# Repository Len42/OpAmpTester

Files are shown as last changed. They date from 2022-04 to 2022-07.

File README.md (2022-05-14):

# Op Amp Tester

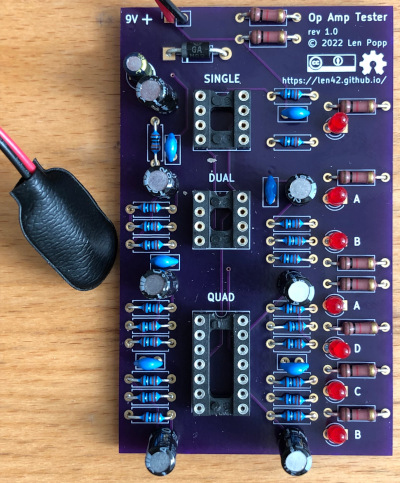
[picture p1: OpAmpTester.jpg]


This is a circuit that tests op amp chips to verify that they are working properly. You might find it useful if you repair old equipment, or if your prototype circuits don't always work the way you expect. 🔥😕

### Features

- Tests single, dual, and quad op amp DIP ICs that have the standard pinout
- LEDs blinking = op amps working!
- Powered by a 9-volt battery

### Usage

The circuit board has separate sockets for single, dual, and quad op amp ICs. To test a chip, insert it in the appropriate socket and plug in a 9-volt battery. The LED(s) next to the chip should start blinking. If one or more of the LEDs don't blink, the chip is bad.

### Notes

This tester can test just about any DIP op amp IC (single, dual, or quad) that can operate on a 9 volt power supply and that has the usual pinout. I have tried it with several chips including:
- TL071, TL074
- LM358
- OPA2134

The circuit is designed for a 9-volt power supply. Using a higher supply voltage may not work because the LEDs can't take much reverse voltage.

The PCB layout is provided in KiCad and gerber formats. The PCBs that I used can be ordered from OSH Park. The design is [here.](https://oshpark.com/shared_projects/9kqx3vmx)

I made a [parts list](OpAmpTester-BOM.csv) with links to specific parts and vendors, but most of the components are generic resistors, capacitors, and LEDs - it's not necessary to use the exact parts that I listed. I do recommend using good quality IC sockets because cheap ones are not designed for repeated IC insertion and removal.

Please note that I am a hobbyist, not a trained electronics engineer. No guarantees!

### References

This design is based on some other op amp testers:

- [Edison Science Corner](https://www.youtube.com/watch?v=aGswFkS5oHQ)  
- [NightFire Electronics](https://vakits.com/single-op-amp-tester-kit)  
- [Synthchaser](https://synthchaser.com/product/synthchaser-op-amp-tester/)  

### Software Used

[KiCad](https://www.kicad.org/) 6.0.4

<hr /><div><div style="xfloat:left; padding-left:10px;"><br />© 2022 Len Popp CC BY<br />This work is licensed under a <a rel="license" href="http://creativecommons.org/licenses/by/4.0/">Creative Commons Attribution 4.0 International License</a>.</div></div>

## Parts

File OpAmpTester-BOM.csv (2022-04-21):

Ref | Qty | Value | Value2 | Note | Description | Datasheet | Manufacturer | ManuPartNum | Distributor1 | DistributorPartNum1 | DistributorPartLink1 | Distributor2 | DistributorPartNum2 | DistributorPartLink2
C1 | 1 | 10U |  |  | Capacitor - Electrolytic | https://www.mouser.ca/datasheet/2/315/ABA0000C1218-1131230.pdf | Panasonic | ECA-1EM100I | Mouser | 667-ECA-1EM100I | https://www.mouser.ca/ProductDetail/Panasonic/ECA-1EM100I?qs=rMMd5vBiahoPyQAc8NWEpA%3D%3D
C2 C5 C6 C9 C10 C11 C12 | 7 | 1U |  |  | Capacitor - Electrolytic | https://www.mouser.ca/datasheet/2/231/161588148197-2307385.pdf | Lelon | SEA010M1HBK-0407P | Mouser | 140-SEA1R0M1HBK0407 | https://www.mouser.ca/ProductDetail/Lelon/SEA010M1HBK-0407P?qs=tsfqLUzc7IqlOdpxXJYLkw%3D%3D
C3 C4 C7 C8 C13 C14 | 6 | 100N |  |  | Capacitor - Ceramic - IC decoupling | https://product.tdk.com/system/files/dam/doc/product/capacitor/ceramic/lead-mlcc/catalog/leadmlcc_halogenfree_fg_en.pdf | TDK | FG18X7R1H104KNT06 | Mouser | 810-FG18X7R1H104KNT6 | https://www.mouser.ca/ProductDetail/810-FG18X7R1H104KNT6
D1 | 1 | 1N4001 |  |  | 50V 1A General Purpose Rectifier Diode, DO-41 | http://www.vishay.com/docs/88503/1n4001.pdf | onsemi | 1N4001RLG | Mouser | 863-1N4001RLG | https://www.mouser.ca/ProductDetail/onsemi/1N4001RLG?qs=y2kkmE52mdNtNRrsA1ylQg%3D%3D
D2 D3 D4 D5 D6 D7 D8 | 7 | LED |  |  | Light emitting diode | https://www.mouser.ca/datasheet/2/239/lite-on_lite-s-a0002934679-1-1737726.pdf | Lite-On | LTL-1CHE | Mouser | 859-LTL-1CHE | https://www.mouser.ca/ProductDetail/Lite-On/LTL-1CHE
J1 | 1 | V-IN |  |  | Generic connector, single row, 01x02, script generated (kicad-library-utils/schlib/autogen/connector/) | https://cdn-shop.adafruit.com/datasheets/00548.pdf |  |  | Adafruit | 598 | https://www.adafruit.com/product/598 | Mouser | 710-61303211821 | https://www.mouser.ca/ProductDetail/Wurth-Elektronik/61303211821?qs=ZtY9WdtwX55M%2FH%2FSrHZ9xA%3D%3D
R1 R2 R6 R10 R14 R18 R22 R26 R30 | 9 | 1K |  |  | Resistor | https://www.mouser.ca/datasheet/2/427/ccf07-1762725.pdf | Vishay / Dale | CCF071K00JKE36 | Mouser | 71-CCF071K00JKE36 | https://www.mouser.ca/ProductDetail/Vishay-Dale/CCF071K00JKE36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
R3 R4 R5 R7 R8 R9 R11 R12 R13 R15 R16 R17 R19 R20 R21 R23 R24 R25 R27 R28 R29 | 21 | 100K |  |  | Resistor | https://www.mouser.ca/datasheet/2/447/Yageo_LR_MFR_1-1714151.pdf | YAGEO | MFR-12FTF52-100K | Mouser | 603-MFR-12FTF52-100K | https://www.mouser.ca/ProductDetail/YAGEO/MFR-12FTF52-100K?qs=oAGoVhmvjhxn7uX6J9%2FOug%3D%3D
U1 | 1 | DUT |  | Socket only | Single Low-Noise JFET-Input Operational Amplifiers, DIP-8/SOIC-8 | https://www.mouser.ca/datasheet/2/273/MMMC_S_A0004812225_1-2556829.pdf | Mill-Max | 110-47-308-41-001000 | Mouser | 575-1104730841001000 | https://www.mouser.ca/ProductDetail/Mill-Max/110-47-308-41-001000?qs=5aG0NVq1C4yjuEd6bRM23w%3D%3D
U2 | 1 | DUT |  | Socket only | Dual Low-Noise JFET-Input Operational Amplifiers, DIP-8/SOIC-8 | https://www.mouser.ca/datasheet/2/273/MMMC_S_A0004812225_1-2556829.pdf | Mill-Max | 110-47-308-41-001000 | Mouser | 575-1104730841001000 | https://www.mouser.ca/ProductDetail/Mill-Max/110-47-308-41-001000?qs=5aG0NVq1C4yjuEd6bRM23w%3D%3D
U3 | 1 | DUT |  | Socket only | Quad Low-Noise JFET-Input Operational Amplifiers, DIP-14/SOIC-14 | https://www.mouser.ca/datasheet/2/273/MMMC_S_A0004813833_1-2556290.pdf | Mill-Max | 110-47-314-41-001000 | Mouser | 575-1104731441001000 | https://www.mouser.ca/ProductDetail/Mill-Max/110-47-314-41-001000?qs=5aG0NVq1C4ysyq77BxEvbg%3D%3D

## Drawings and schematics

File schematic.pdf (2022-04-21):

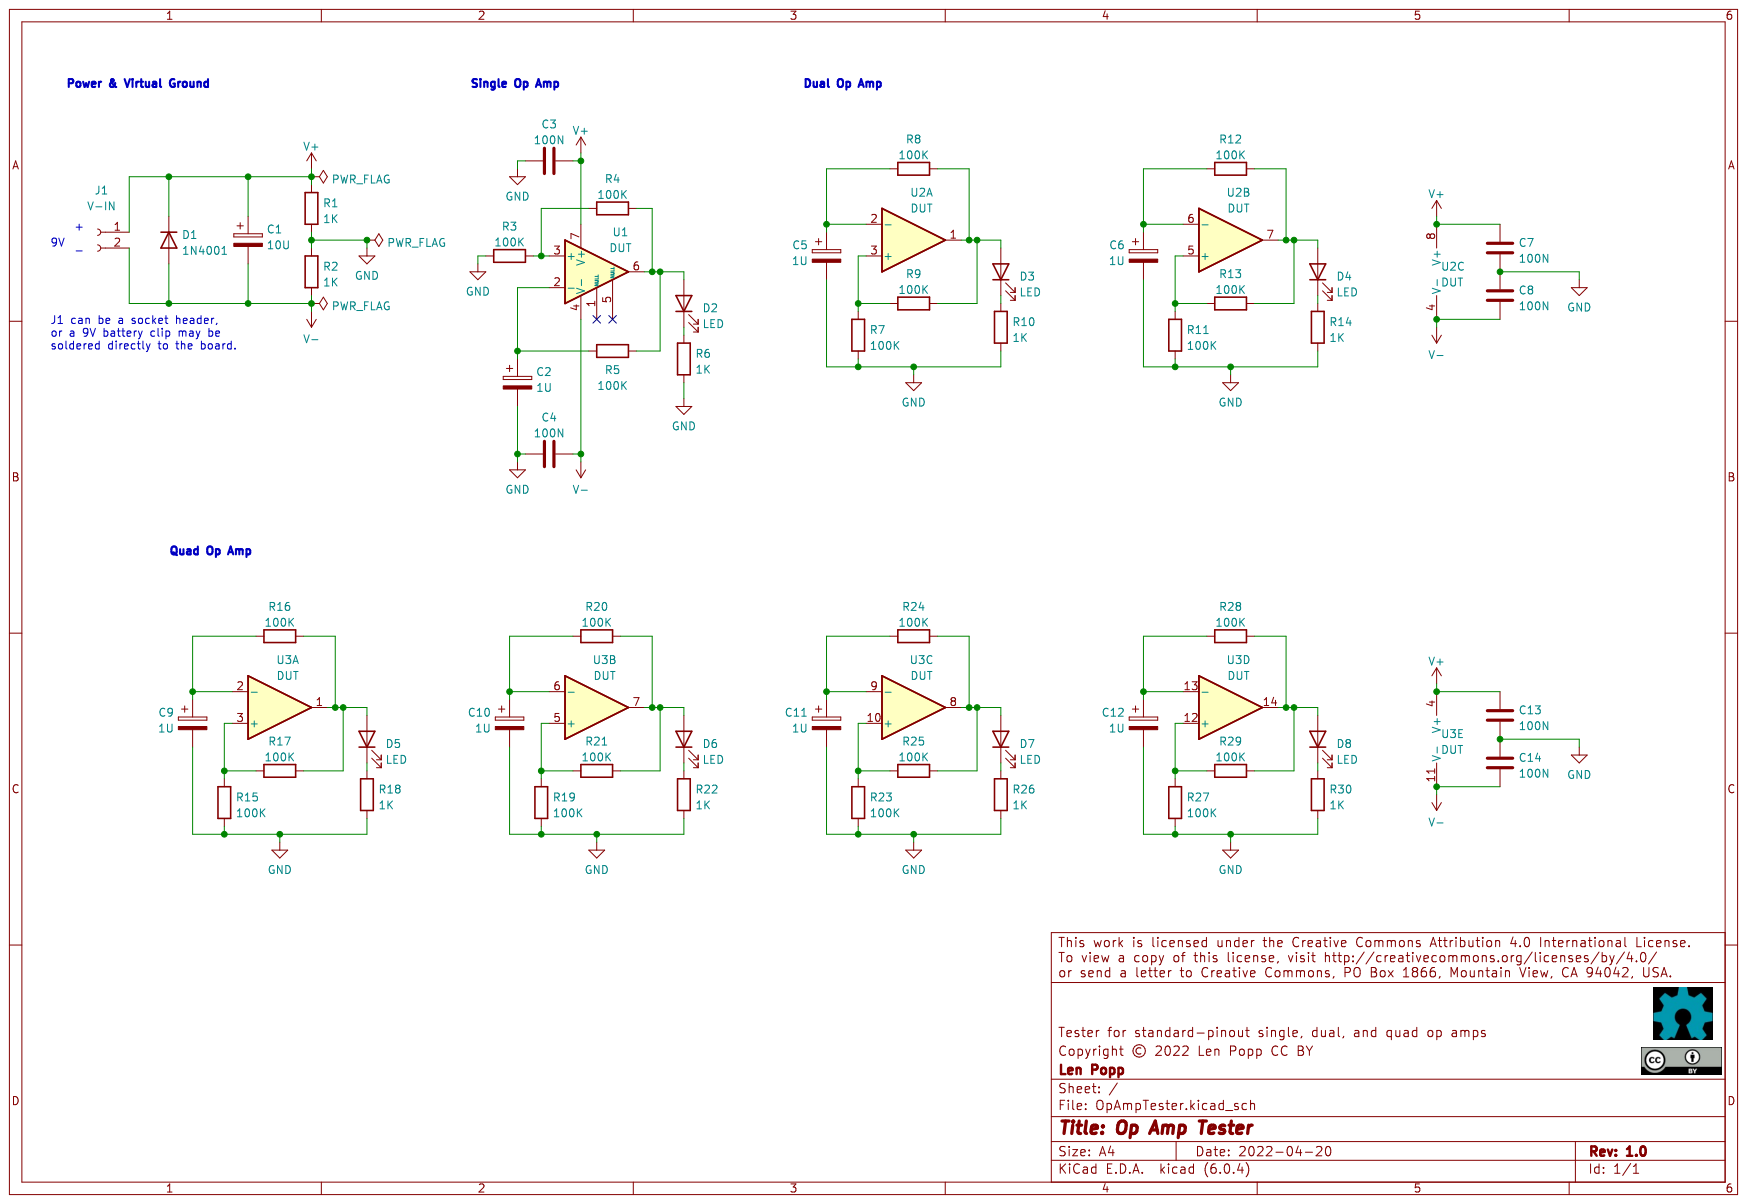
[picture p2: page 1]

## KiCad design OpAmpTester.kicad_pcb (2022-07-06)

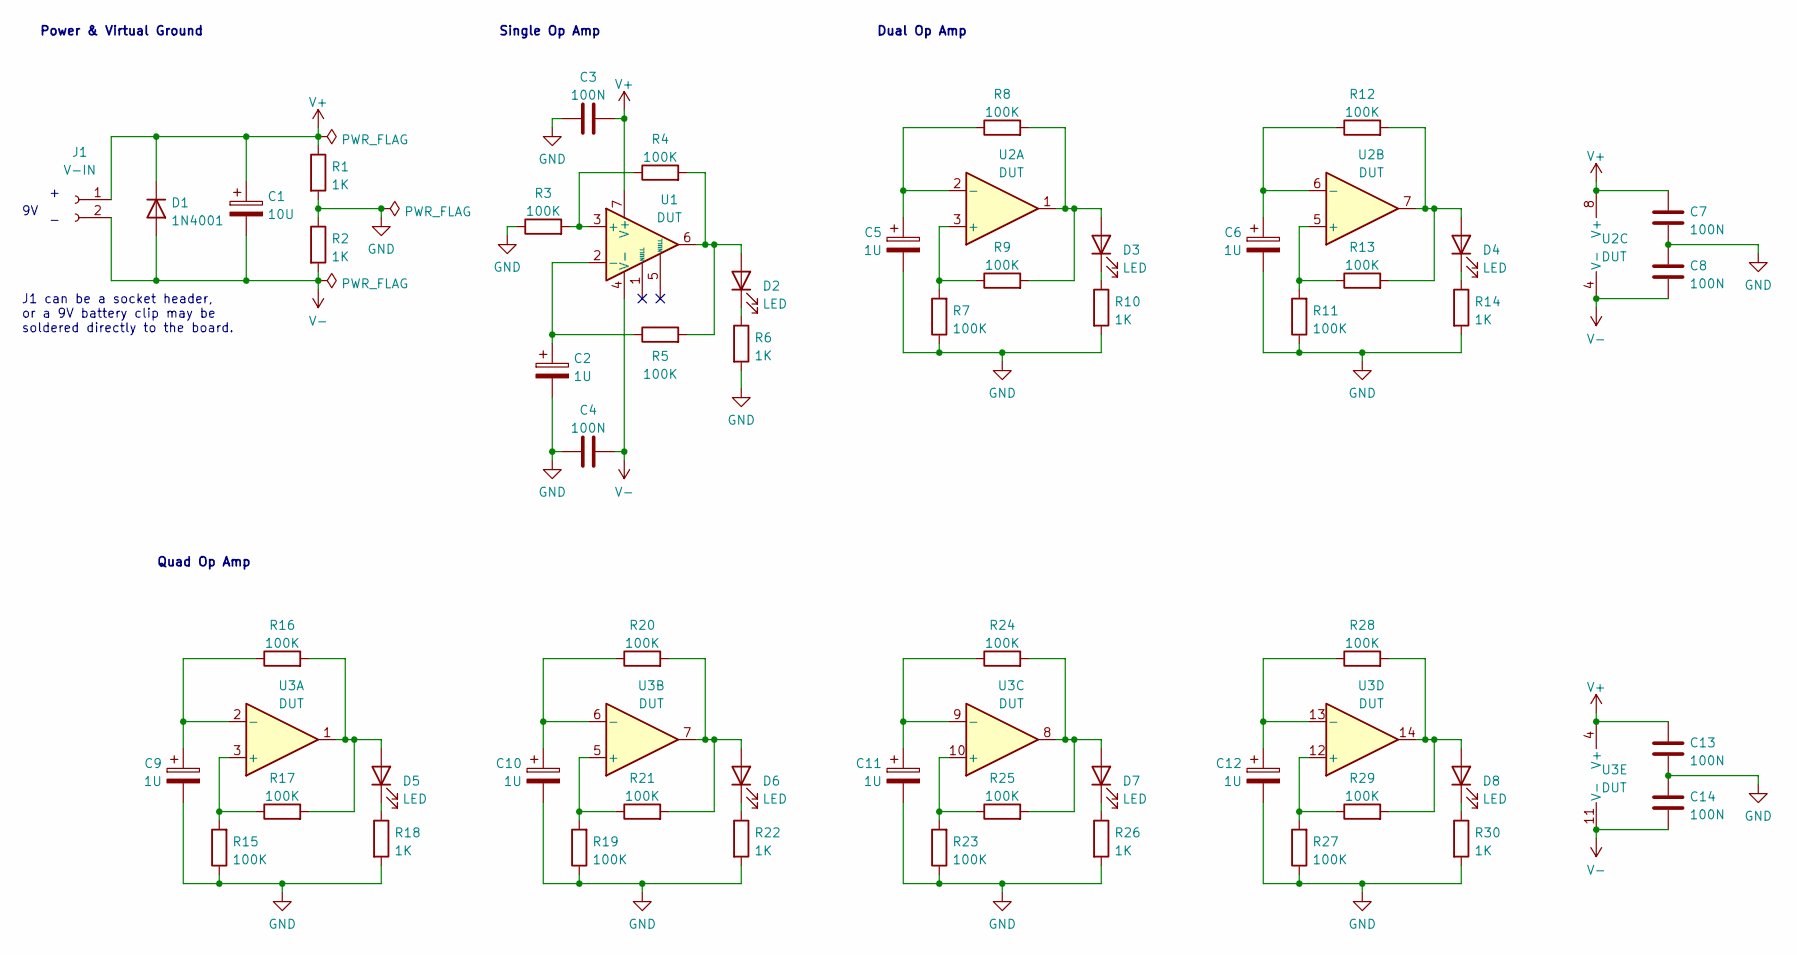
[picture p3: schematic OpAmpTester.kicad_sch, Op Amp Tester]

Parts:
C1: 10U; CP_Radial_D5.0mm_P2.50mm; ManufacturerPartNum ECA-1EM100I
C2, C5, C6, C9, C10, C11, C12: 1U; CP_Radial_D4.0mm_P2.50mm; ManufacturerPartNum SEA010M1HBK-0407P
C3, C4, C7, C8, C13, C14: 100N; C_Disc_D5.0mm_W2.5mm_P2.50mm; ManufacturerPartNum FG18X7R1H104KNT06
D1: 1N4001; D_DO-41_SOD81_P10.16mm_Horizontal; ManufacturerPartNum 1N4001RLG
D2, D3, D4, D5, D6, D7, D8: LED; LED_D3.0mm; ManufacturerPartNum LTL-1CHE
J1: V-IN; PinSocket_1x02_P2.54mm_Vertical
R1, R2, R6, R10, R14, R18, R22, R26, R30: 1K; R_Axial_DIN0207_L6.3mm_D2.5mm_P10.16mm_Horizontal; ManufacturerPartNum CCF071K00JKE36
R3, R4, R5, R7, R8, R9, R11, R12, R13, R15, R16, R17, R19, R20, R21, R23, R24, R25, R27, R28, R29: 100K; R_Axial_DIN0207_L6.3mm_D2.5mm_P7.62mm_Horizontal; ManufacturerPartNum MFR-12FTF52-100K
U1, U2: DUT; DIP-8_W7.62mm_Socket; ManufacturerPartNum 110-47-308-41-001000
U3: DUT; DIP-14_W7.62mm_Socket; ManufacturerPartNum 110-47-314-41-001000

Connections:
GND: C2.2, C3.1, C4.1, C5.2, C6.2, C7.2, C8.1, C9.2, C10.2, C11.2, C12.2, C13.2, C14.1, R1.2, R2.1, R3.1, R6.2, R7.1, R10.2, R11.1, R14.2, R15.1, R18.2, R19.1, R22.2, R23.1, R26.2, R27.1, R30.2
unnamed: C2.1, R5.1, U1.2 (-)
unnamed: C5.1, R8.1, U2.2 (-)
unnamed: C6.1, R12.1, U2.6 (-)
unnamed: C9.1, R16.1, U3.2 (-)
unnamed: C10.1, R20.1, U3.6 (-)
unnamed: C11.1, R24.1, U3.9 (-)
unnamed: C12.1, R28.1, U3.13 (-)
unnamed: D2.1 (K), R6.1
unnamed: D2.2 (A), R4.2, R5.2, U1.6
unnamed: D3.1 (K), R10.1
unnamed: D3.2 (A), R8.2, R9.2, U2.1
unnamed: D4.1 (K), R14.1
unnamed: D4.2 (A), R12.2, R13.2, U2.7
unnamed: D5.1 (K), R18.1
unnamed: D5.2 (A), R16.2, R17.2, U3.1
unnamed: D6.1 (K), R22.1
unnamed: D6.2 (A), R20.2, R21.2, U3.7
unnamed: D7.1 (K), R26.1
unnamed: D7.2 (A), R24.2, R25.2, U3.8
unnamed: D8.1 (K), R30.1
unnamed: D8.2 (A), R28.2, R29.2, U3.14
unnamed: R3.2, R4.1, U1.3 (+)
unnamed: R7.2, R9.1, U2.3 (+)
unnamed: R11.2, R13.1, U2.5 (+)
unnamed: R15.2, R17.1, U3.3 (+)
unnamed: R19.2, R21.1, U3.5 (+)
unnamed: R23.2, R25.1, U3.10 (+)
unnamed: R27.2, R29.1, U3.12 (+)
V+: C1.1, C3.2, C7.1, C13.1, D1.1 (K), J1.1, R1.1, U1.7 (V+), U2.8 (V+), U3.4 (V+)
V-: C1.2, C4.2, C8.2, C14.2, D1.2 (A), J1.2, R2.2, U1.4 (V-), U2.4 (V-), U3.11 (V-)

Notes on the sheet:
Single Op Amp
J1 can be a socket header, or a 9V battery clip may be soldered directly to the board.
Dual Op Amp
Quad Op Amp
Power & Virtual Ground

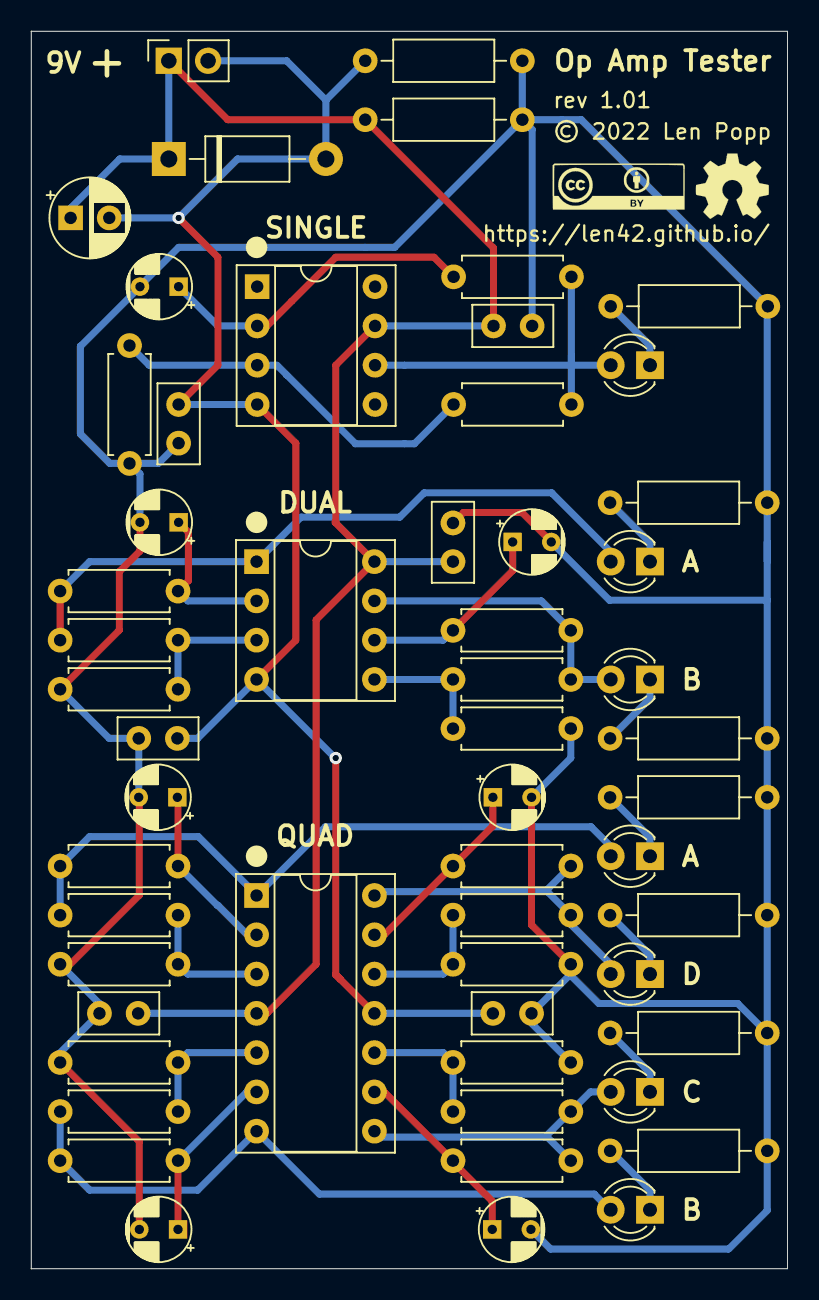
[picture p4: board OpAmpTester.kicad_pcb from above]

Board: 2 copper layers, 48.9 x 80.0 mm, 56 parts (0 on the bottom side), 31 nets.

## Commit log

2022-04-20 Op Amp Tester version 1.0
    [OpAmpTester.kicad_pcb, OpAmpTester.kicad_sch]
2022-04-21 add the KiCad page layout file
2022-04-21 BOM file
    [OpAmpTester-BOM.csv, OpAmpTester.kicad_pcb, OpAmpTester.kicad_sch]
2022-04-21 schematic tweaks
    [OpAmpTester.kicad_pcb, OpAmpTester.kicad_sch]
2022-07-06 Add pin-1 indicators for sockets
    [OpAmpTester.kicad_pcb]

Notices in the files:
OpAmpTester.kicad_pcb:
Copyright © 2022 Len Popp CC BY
